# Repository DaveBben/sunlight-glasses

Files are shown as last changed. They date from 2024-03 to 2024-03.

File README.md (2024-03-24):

# Sunlight Glasses inspired by Dr. Andrew Huberman

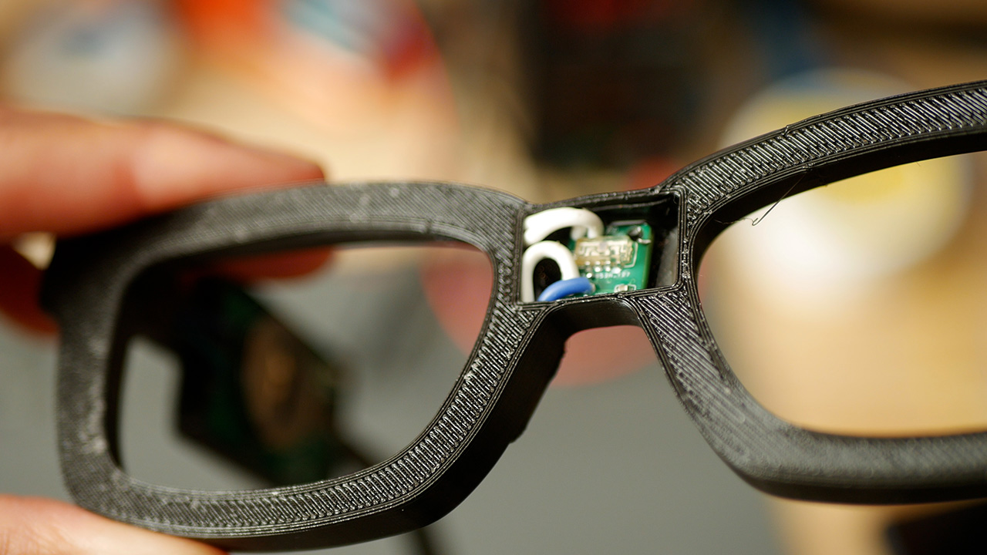
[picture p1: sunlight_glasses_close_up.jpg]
Sunlight Glasses


Dr. Andrew Huberman is really big on sunlight exposure. It has positive effects on mood, sleep, cognition and so much more. In an interview with Dr. Peter Attia, Huberman said it would be great if there was an invention to let the user know when they have achieved enough sunlight during the day. Furthermore, notify them if they are looking at too much light at nighttime.

This gadget is built to do just that. Inside of these 3D printed glasses frame I created a custom PCB using the NRF52. 

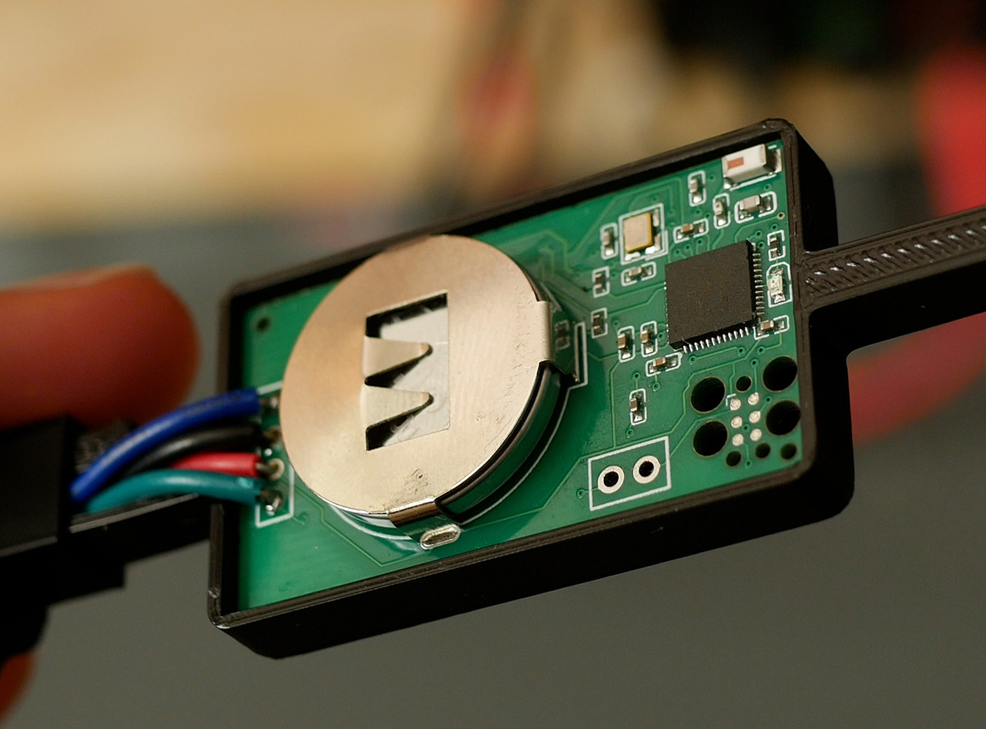
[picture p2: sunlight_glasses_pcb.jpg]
Sunlight Glasses PCB

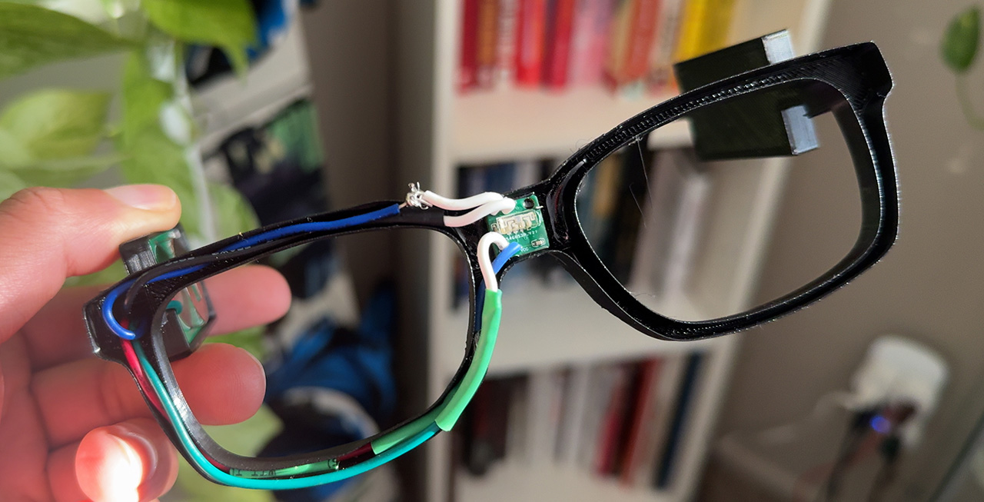
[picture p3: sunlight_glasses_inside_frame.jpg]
Sunlight Glasses Wiring


It reads ambient light from the VEML7700 located in between the eyes of the frame and sends it via BLE to an IOS app. (I make use of the Environmental Sensing Service profile and Perceived Light Characteristic).

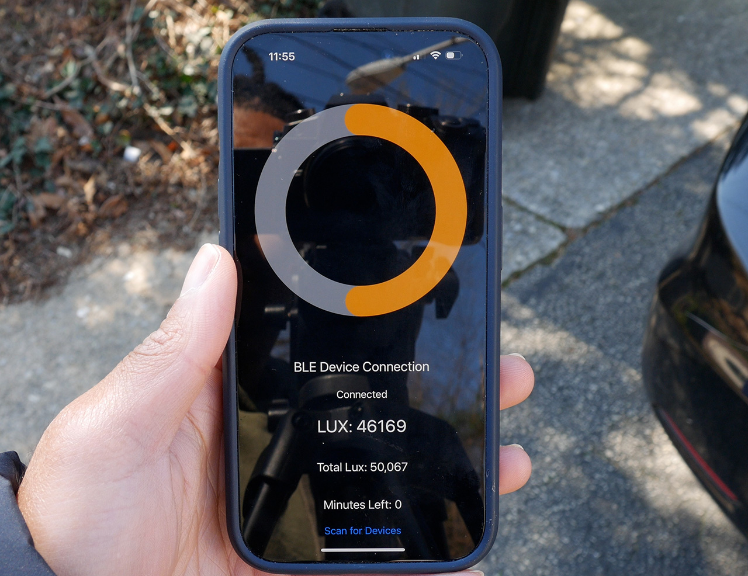
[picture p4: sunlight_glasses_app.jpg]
Sunlight Glasses App


The IOS app receives the ambient light value every second and calculates the average once per minute. It then tells you how many total LUX that you have received. Furthermore, given the total lux it will tell you how many minutes it would take to reach 100K LUX given the current LUX.

## Links:
YouTube Video: https://www.youtube.com/watch?v=xIHv9QHtEUs

Detailed Blog Post: https://www.bennettnotes.com/projects/sunlight_glasses_inspired_by_andrew_huberman/

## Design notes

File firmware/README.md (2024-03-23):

# Sunlight Glasses Embedded Software 
This is the software for the NRF52810. It uses Zephyr RTOS. It reads the ambient light value and reports it to the connected device. It is setup to use the **Environmental Sensing** service with the **Perceived Lightness** characteristic.

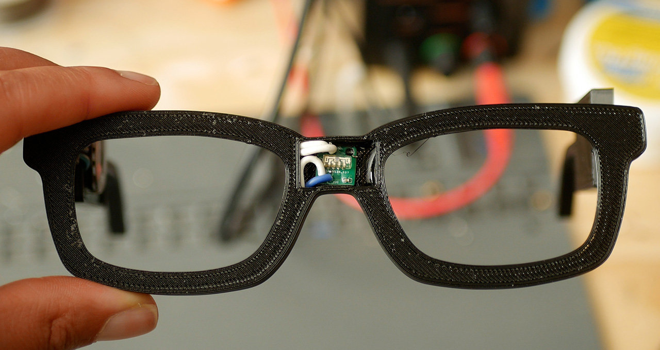
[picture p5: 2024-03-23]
sunlight_glasses_frame.jpg

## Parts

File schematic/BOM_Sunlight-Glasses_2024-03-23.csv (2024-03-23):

ID | Name | Designator | Footprint | Quantity | Manufacturer Part | Manufacturer | Supplier | Supplier Part | Price
1 | 2450AT18A100E | AE1 | ANT-SMD_L3.2-W1.6 | 1 | 2450AT18A100E | JOHANSON(约翰逊) | LCSC | C89334 | 0.468
2 | 4.7uF | C2 | C0402 | 1 | CL05A475MP5NRNC | SAMSUNG(三星) | LCSC | C23733 | 0.006
3 | 100pF | C3 | C0402 | 1 | 0402CG101J500NT | FH(风华) | LCSC | C1546 | 0.001
4 | 1uF | C5 | C0402 | 1 | CL05A105KA5NQNC | SAMSUNG(三星) | LCSC | C52923 | 0.004
5 | 100nF | C7,C8,C9,C10 | C0402 | 4 | CL05B104KB54PNC | SAMSUNG(三星) | LCSC | C307331 | 0.006
6 | 12pF | C11,C12 | C0402 | 2 | 0402CG120J500NT | FH(风华) | LCSC | C1547 | 0.001
7 | 0.8pF | C6 | C0603 | 1 | Murata Electronics | Murata Electronics | LCSC | C907996 | 0.035
8 | STLINK_TC2030 | J2 | TAG-CONNECT_TC2030-IDC-FP | 1
9 | 3.9nH | L1 | L0402 | 1 | SDCL1005C3N9STDF | Sunlord(顺络) | LCSC | C14033 | 0.003
10 | KT-0603R | LED1 | LED0603-RD | 1 | KT-0603R | KENTO | LCSC | C2286 | 0.006
11 | 470Ω | R1 | R0402 | 1 | 0402WGF4700TCE | UNI-ROYAL(厚声) | LCSC | C25117 | 0.001
12 | - | U1 | UQFN-48_L6.0-W6.0-P0.40-BL-EP4.6 | 1 | NRF52810-QFAA-R | NORDIC | LCSC | C141828 | 2.967
13 | MY-2032-02 | U2 | BATT-TH_MY-2032-02 | 1 | MY-2032-02 | MYOUNG(美阳) | LCSC | C964822 | 0.125
14 | Extra Power Connectors | U4 | TWO_PINS | 1
15 | 32MHz | X1 | CRYSTAL-SMD_4P-L2.5-W2.0-BL | 1 | S2232000082060 | JGHC(晶光华) | LCSC | C479187 | 0.07
16 | I2C P1 | KEYPAD1 | I2C KEYAD I2C (4 PIN) | 1
17 | 2.2kΩ | R2,R3 | R0402 | 2 | 0402WGF2201TCE | UNI-ROYAL(厚声) | LCSC | C25879 | 0.001

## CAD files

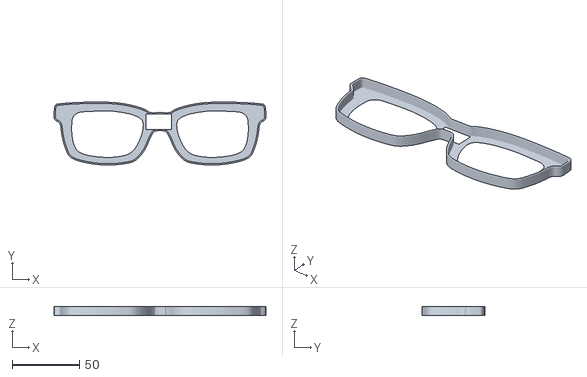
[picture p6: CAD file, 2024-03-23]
CAD/Sunlight_Glasses_Frame_Cover.stl
157.6 x 46.8 x 6.40

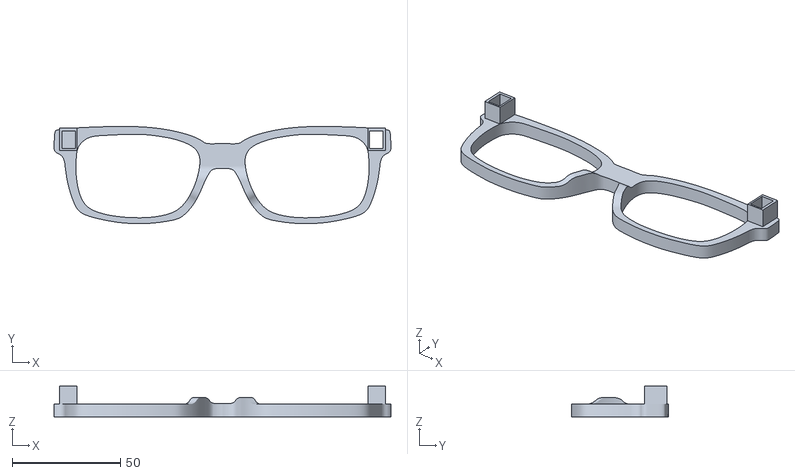
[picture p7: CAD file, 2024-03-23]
CAD/Sunlight_Glasses_Frame.stl
155.6 x 44.8 x 14.1

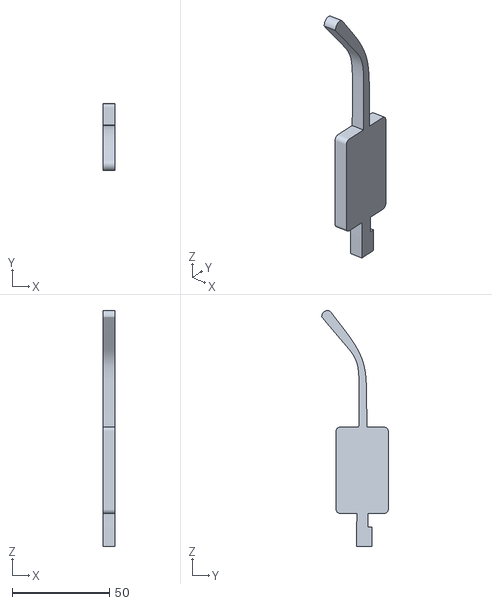
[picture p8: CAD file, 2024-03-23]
CAD/Sunlight_Glasses_Leg.stl
6.00 x 34.2 x 121.1

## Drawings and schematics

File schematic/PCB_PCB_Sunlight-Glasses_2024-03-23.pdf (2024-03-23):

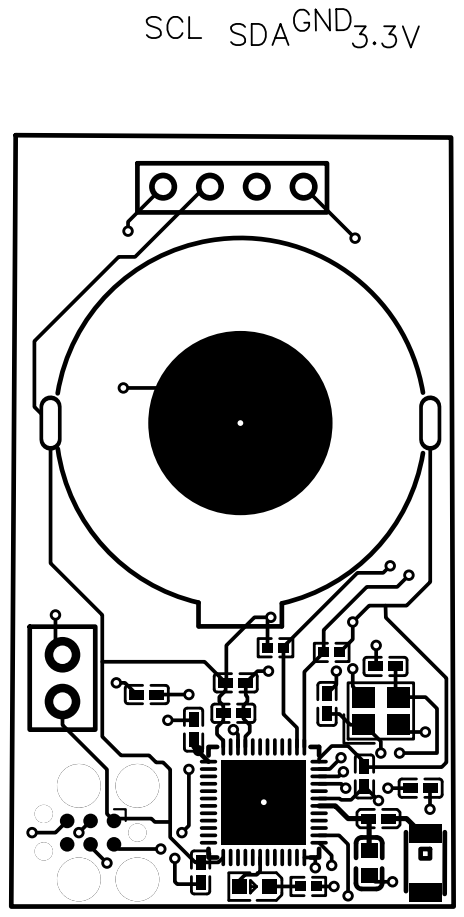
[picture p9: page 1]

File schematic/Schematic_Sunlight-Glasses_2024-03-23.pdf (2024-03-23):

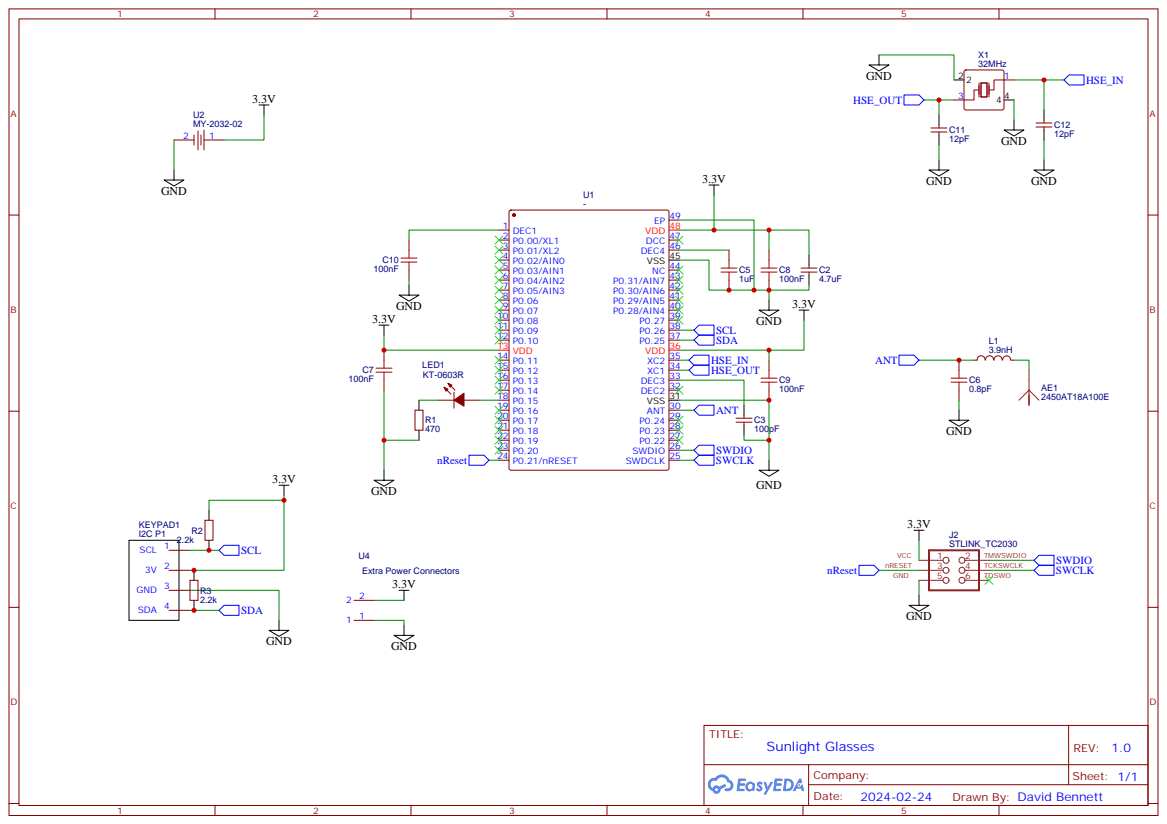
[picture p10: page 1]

Drawn By: David Bennett

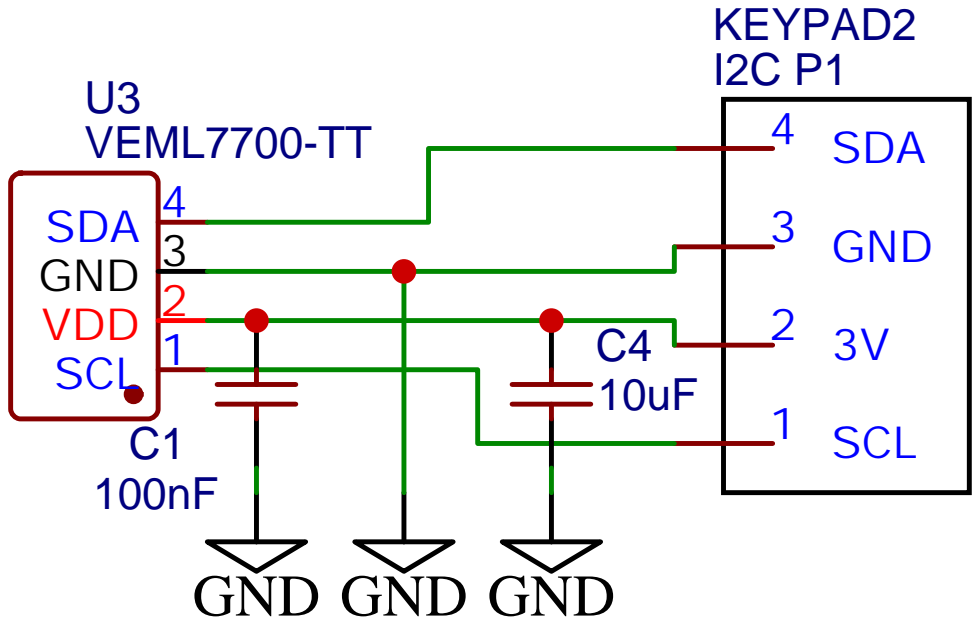
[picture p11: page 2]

Drawn By: David Bennett

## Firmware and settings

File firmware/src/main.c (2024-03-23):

/* main.c - Application main entry point */
/* Reads and reports ambient light value */

/*
 * Copyright (c) 2015-2016 Intel Corporation
 *
 * SPDX-License-Identifier: Apache-2.0
 */

#include <zephyr/types.h>
#include <stddef.h>
#include <string.h>
#include <errno.h>
#include <zephyr/sys/printk.h>
#include <zephyr/sys/byteorder.h>
#include <zephyr/kernel.h>
#include <zephyr/drivers/sensor.h>
#include <zephyr/drivers/sensor/veml7700.h>
#include <zephyr/device.h>

#include <zephyr/bluetooth/bluetooth.h>
#include <zephyr/bluetooth/hci.h>
#include <zephyr/bluetooth/conn.h>
#include <zephyr/bluetooth/uuid.h>
#include <zephyr/bluetooth/gatt.h>
#include <zephyr/bluetooth/services/bas.h>
#include <zephyr/bluetooth/services/ias.h>
#include "ess.h"

static const struct bt_data ad[] = {
	BT_DATA_BYTES(BT_DATA_FLAGS, (BT_LE_AD_GENERAL | BT_LE_AD_NO_BREDR)),
	BT_DATA_BYTES(BT_DATA_UUID16_ALL,
				  BT_UUID_16_ENCODE(BT_UUID_ESS_VAL),
				  BT_UUID_16_ENCODE(BT_UUID_BAS_VAL),
				  BT_UUID_16_ENCODE(BT_UUID_DIS_VAL))};

static void connected(struct bt_conn *conn, uint8_t err)
{
	if (err)
	{
		printk("Connection failed (err 0x%02x)\n", err);
	}
	else
	{
		printk("Connected\n");
	}
}

static void disconnected(struct bt_conn *conn, uint8_t reason)
{
	printk("Disconnected (reason 0x%02x)\n", reason);
}

BT_CONN_CB_DEFINE(conn_callbacks) = {
	.connected = connected,
	.disconnected = disconnected,
};

static void bt_ready(void)
{
	int err;

	printk("Bluetooth initialized\n");

	err = bt_le_adv_start(BT_LE_ADV_CONN_NAME, ad, ARRAY_SIZE(ad), NULL, 0);
	if (err)
	{
		printk("Advertising failed to start (err %d)\n", err);
		return;
	}

	printk("Advertising successfully started\n");
}

static void auth_cancel(struct bt_conn *conn)
{
	char addr[BT_ADDR_LE_STR_LEN];

	bt_addr_le_to_str(bt_conn_get_dst(conn), addr, sizeof(addr));

	printk("Pairing cancelled: %s\n", addr);
}

static struct bt_conn_auth_cb auth_cb_display = {
	.cancel = auth_cancel,
};

static void bas_notify(void)
{
	uint8_t battery_level = bt_bas_get_battery_level();

	battery_level--;

	if (!battery_level)
	{
		battery_level = 100U;
	}

	bt_bas_set_battery_level(battery_level);
}

static const struct device *get_veml7700_device(void)
{
	const struct device *const dev = DEVICE_DT_GET_ANY(vishay_veml7700);

	if (dev == NULL)
	{
		/* No such node, or the node does not have status "okay". */
		printk("\nError: no device found.\n");
		return NULL;
	}

	if (!device_is_ready(dev))
	{
		printk("\nError: Device \"%s\" is not ready; "
			   "check the driver initialization logs for errors.\n",
			   dev->name);
		return NULL;
	}

	printk("Found device \"%s\", getting sensor data\n", dev->name);
	return dev;
}

int main(void)
{
	int err;

	err = bt_enable(NULL);
	if (err)
	{
		printk("Bluetooth init failed (err %d)\n", err);
		return 0;
	}

	bt_ready();

	bt_conn_auth_cb_register(&auth_cb_display);

	const struct device *dev = get_veml7700_device();
	struct sensor_value ambient_light;

	// Need to set gain levels for high lux value
	// Can also override driver constructor if nedded
	if (sensor_attr_set(dev, SENSOR_CHAN_LIGHT, SENSOR_ATTR_VEML7700_GAIN, VEML7700_ALS_GAIN_1_8) != 0)
	{
		return 0;
	};
	if(sensor_attr_set(dev, SENSOR_CHAN_LIGHT, SENSOR_ATTR_VEML7700_ITIME, VEML7700_ALS_IT_25) != 0)
	{
		return 0;
	};

	if (dev == NULL)
	{
		printk("Device not found");
		return 0;
	}


	while (1)
	{
		sensor_sample_fetch(dev);
		sensor_channel_get(dev, SENSOR_CHAN_LIGHT, &ambient_light);
		printk("lux: %d\n",
			   ambient_light.val1);

		// Update Light level
		bt_ess_set_light_level(ambient_light.val1);

		// Not implemented just a simulation
		bas_notify();

		k_sleep(K_SECONDS(1));
	}
	return 0;
}

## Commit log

2024-03-23 inital commit
    [BOM_Sunlight-Glasses_2024-03-23 copy.csv, BOM_Sunlight-Glasses_2024-03-23.csv, PickAndPlace_PCB_Sunlight-Glasses_2024-03-23.csv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]
2024-03-23 updates to readme and folder names
    [BOM_Sunlight-Glasses_2024-03-23 copy.csv, BOM_Sunlight-Glasses_2024-03-23.csv, PickAndPlace_PCB_Sunlight-Glasses_2024-03-23.csv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]
2024-03-23 add cad files
    [Sunlight_Glasses_Frame.stl, Sunlight_Glasses_Frame_Cover.stl, Sunlight_Glasses_Leg.stl]
